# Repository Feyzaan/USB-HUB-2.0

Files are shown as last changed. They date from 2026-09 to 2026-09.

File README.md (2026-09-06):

# GL850G + TPS2044B USB Hub — Validation Board

A self-powered, 4-port USB 2.0 hub PCB built to validate independent per-port power switching and fault isolation before use in a larger project. Each downstream port can be individually enabled, current-limited, and fault-reported — a short or overcurrent event on one port never affects the others.

## Overview

Most low-cost USB hubs share power switching across all ports in a single "gang" — one fault trips every port at once. This board is designed the other way: each port has its own dedicated enable and fault-report line, driven by a hub controller running in **individual power mode**, with the actual current-limiting handled by a separate quad power-distribution switch.

This board exists purely to validate that architecture in isolation — no other subsystems, no assumptions carried over from a datasheet reference circuit without independent verification.

## Key Features

- **Independent per-port power switching** — each of the 4 downstream ports has its own enable/fault signal pair, not a shared gang-mode circuit
- **Active overcurrent protection** — a fault on one port trips only that port's power channel; the remaining ports continue operating normally
- **Self-powered architecture** — the hub sources its own downstream power rather than drawing everything from the host's USB port budget
- **Reverse-current protection** — a P-channel MOSFET on the USB-C input blocks the board's local supply from backfeeding into the host
- **USB Type-C current advertisement** — CC-line resistors advertise 1.5 A to the host instead of the USB 2.0 default of 500 mA, using passive resistors only (no PD controller)
- **Per-port status indication** — dual-color LEDs report each port's connection/fault state
- **Independent, isolated crystal oscillators** — the hub controller and any downstream logic run on separate, dedicated clock sources

## Hardware

| Function | Part |
|---|---|
| USB hub controller | Genesys Logic GL850G-MNG21 (LQFP48, individual power mode) |
| Power distribution switch | Texas Instruments TPS2044BDR (quad, independently current-limited channels) |
| Reverse-current blocking | SI2301 P-channel MOSFET |
| Host connector | USB-C (16-pin, reversible) |
| Downstream connectors | 4× USB-A |
| Status indication | Dual-color (green/amber) LEDs, one per port |

## Design Notes

- The hub controller's power-on strap pins configure port count, power-switch polarity, and per-port removable/non-removable status; several of these pins double as status-LED drivers after the strap window closes, requiring careful resistor sizing so the two functions don't interfere with each other.
- Overcurrent-report lines are open-drain and require external pull-ups — this is easy to miss if relying on a symbol's default connections rather than the manufacturer's application circuit.
- Reset sensing is derived from the raw, upstream USB VBUS rail (ahead of the reverse-blocking MOSFET) rather than the board's own regulated rail, so a cable disconnect is detected immediately rather than after the local bulk capacitance discharges.

## Status

Schematic complete and cross-checked pin-by-pin against manufacturer datasheets. PCB fabrication in progress.

## Gallery

**3D render**

<p float="left">
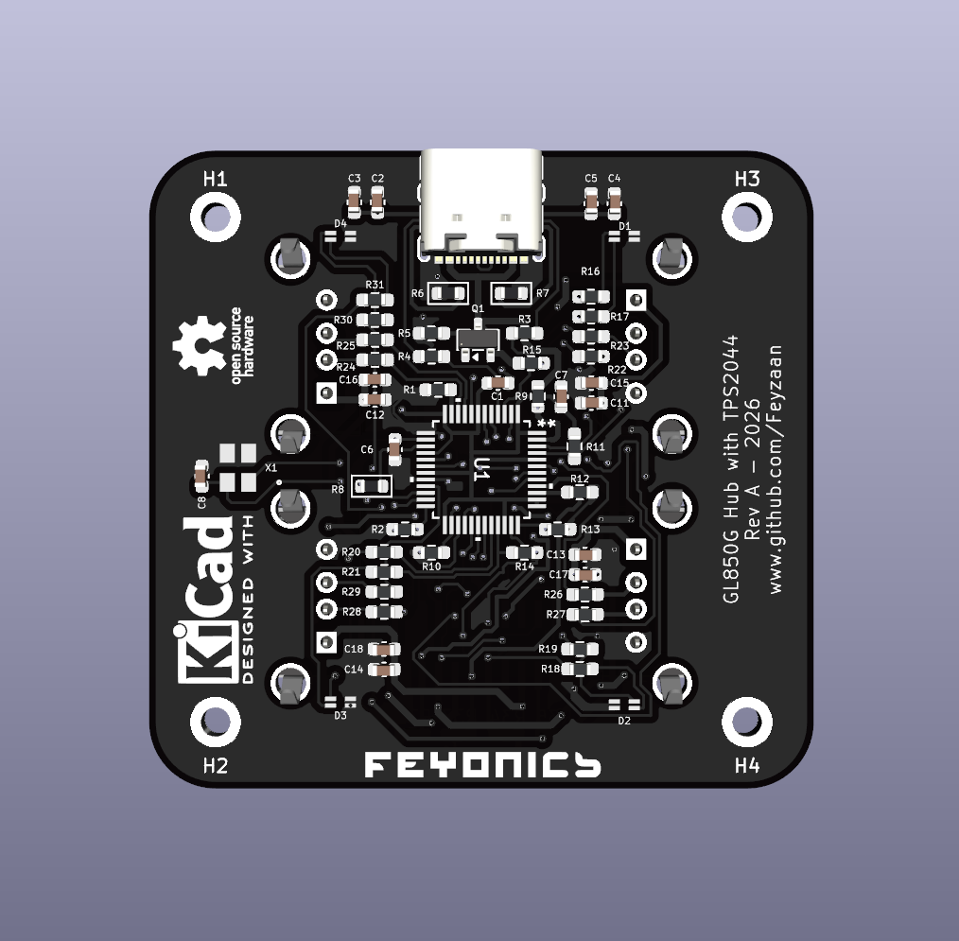
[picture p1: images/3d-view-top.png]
3D render, top view
  
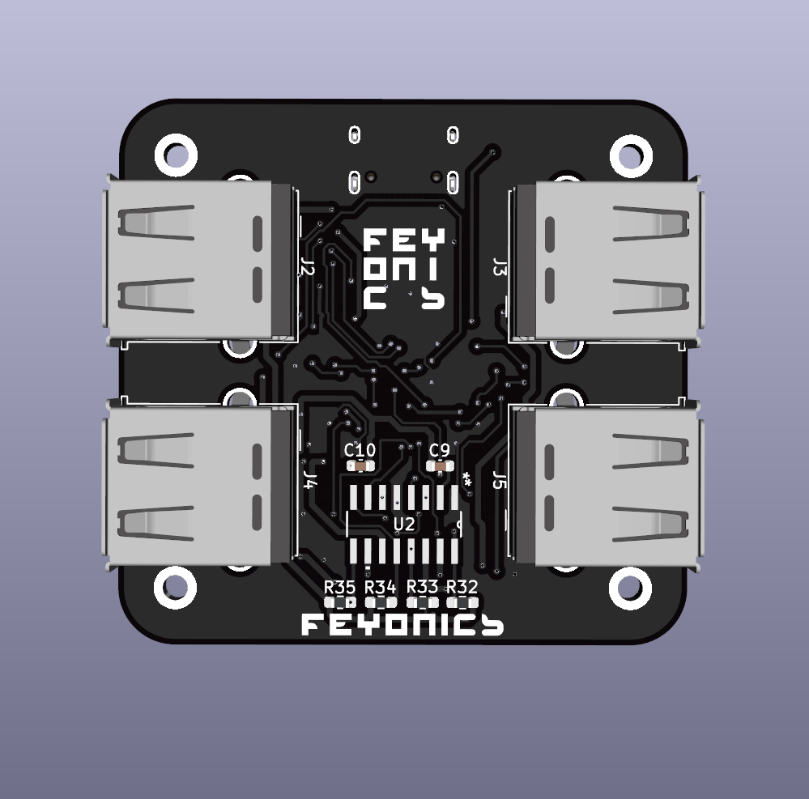
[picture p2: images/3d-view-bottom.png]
3D render, bottom view
  
</p>

**Copper layers**

<p float="left">
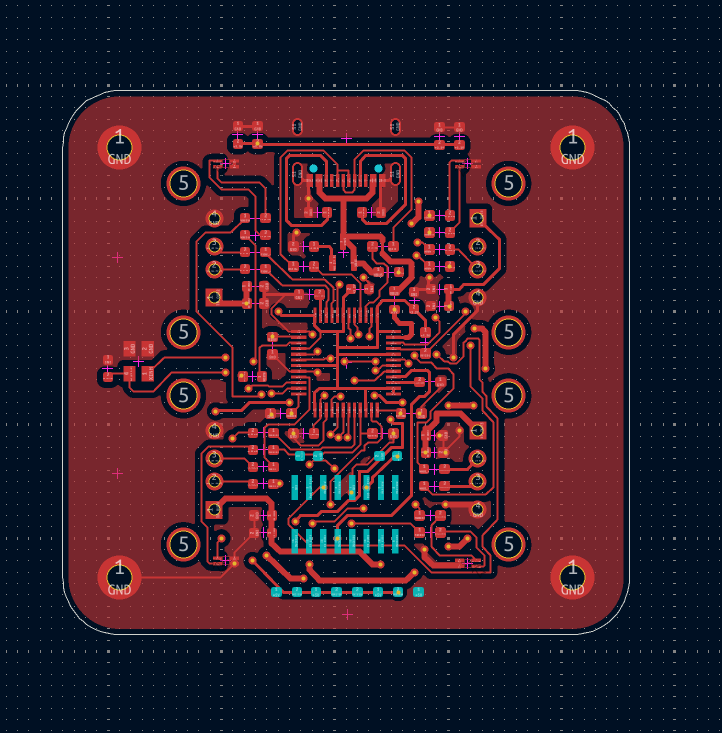
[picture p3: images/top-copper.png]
Top copper layer
  
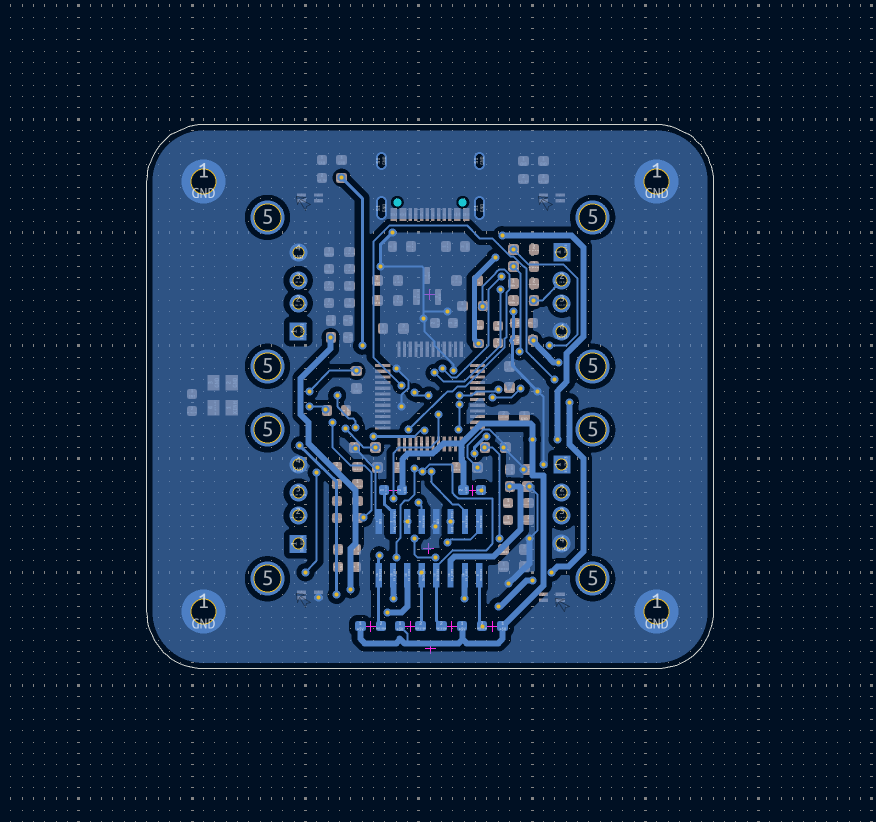
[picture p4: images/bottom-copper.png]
Bottom copper layer
  
</p>

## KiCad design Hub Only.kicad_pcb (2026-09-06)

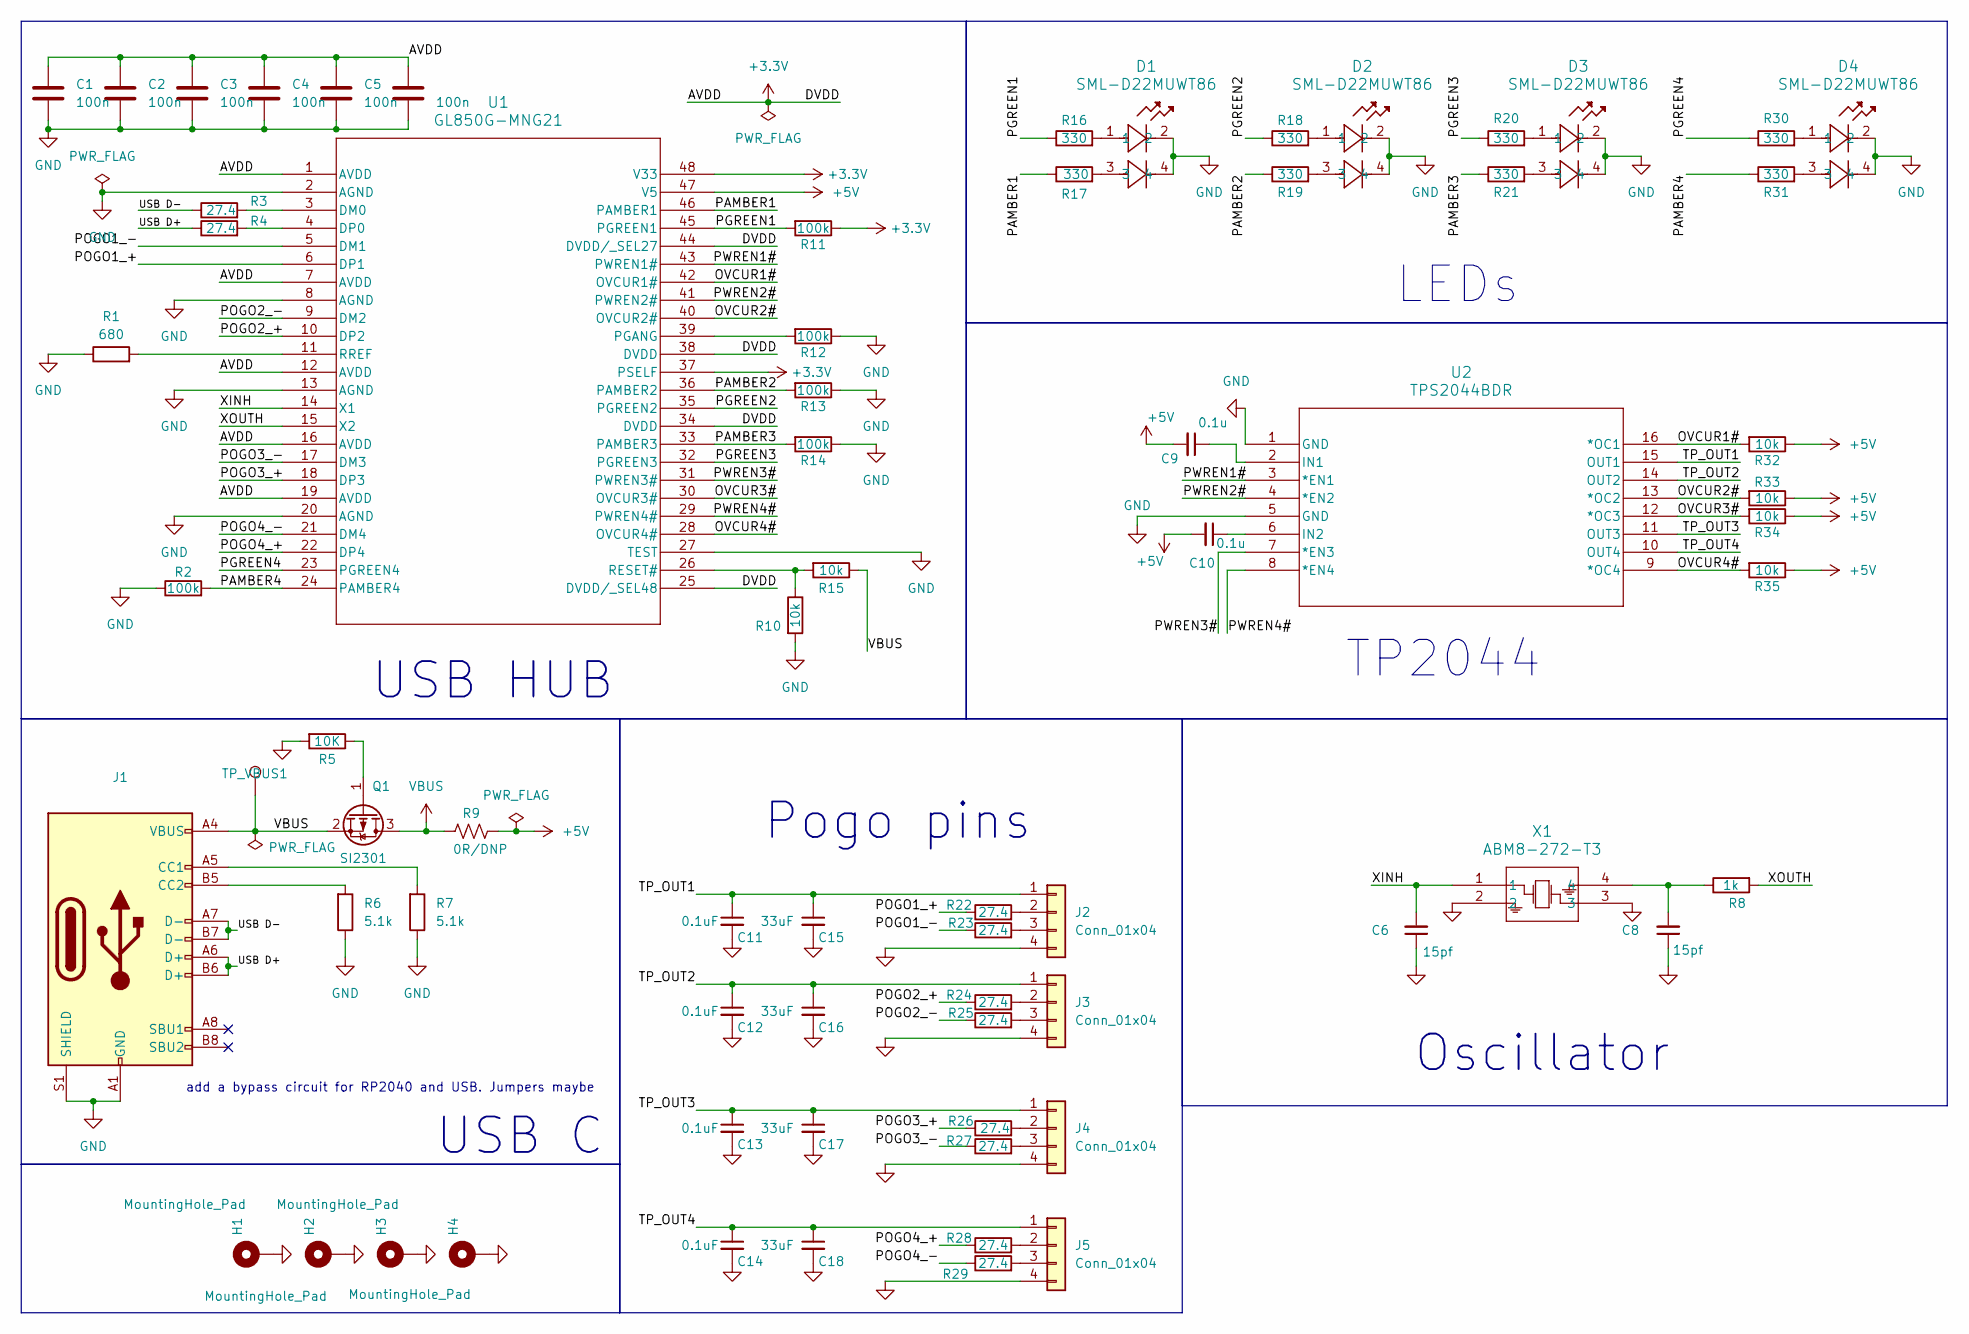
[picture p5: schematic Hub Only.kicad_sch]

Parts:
C1, C2, C3, C4, C5, C7: 100n; C_0603_1608Metric
C6, C8: 15pf; C_0603_1608Metric
C9, C10: 0.1u; C_0603_1608Metric
C11, C12, C13, C14: 0.1uF; C_0603_1608Metric
C15, C16, C17, C18: 33uF; C_0603_1608Metric
D1, D2, D3, D4: SML-D22MUWT86; LED_SML-D22_ROM
H1, H2, H3, H4: MountingHole_Pad; MountingHole_2.2mm_M2_DIN965_Pad
J1: USB_C_Receptacle_XKB_U262-16XN-4BVC11
J2, J3, J4, J5: Conn_01x04; USB_A_Molex_67643_Horizontal
Q1: SI2301; SOT-23
R1: 680; R_0603_1608Metric_Pad0.98x0.95mm_HandSolder
R2, R11, R12, R13, R14: 100k; R_0603_1608Metric_Pad0.98x0.95mm_HandSolder
R3, R4, R22, R23, R24, R25, R26, R27, R28, R29: 27.4; R_0603_1608Metric_Pad0.98x0.95mm_HandSolder
R5: 10K; R_0603_1608Metric_Pad0.98x0.95mm_HandSolder
R6, R7: 5.1k; R_0603_1608Metric
R8: 1k; R_0603_1608Metric
R9: 0R/DNP; R_0603_1608Metric
R10, R15, R32, R33, R34, R35: 10k; R_0603_1608Metric_Pad0.98x0.95mm_HandSolder
R16, R17, R18, R19, R20, R21, R30, R31: 330; R_0603_1608Metric_Pad0.98x0.95mm_HandSolder
TP_VBUS1: TestPoint; TestPoint_Pad_D1.0mm
U1: GL850G-MNG21; QFN48_GL850G_7x7-0P5_GEN
U2: TPS2044BDR; D16
X1: ABM8-272-T3; ABM8-272-T3_ABR

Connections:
+3.3V: C1.2, C2.2, C3.2, C4.2, C5.2, C7.2, R11.1, U1.1 (AVDD), U1.7 (AVDD), U1.12 (AVDD), U1.16 (AVDD), U1.19 (AVDD), U1.25 (DVDD/_SEL48), U1.34 (DVDD), U1.37 (PSELF), U1.38 (DVDD), U1.44 (DVDD/_SEL27), U1.48 (V33)
+5V: C9.2, C10.2, R9.2, R32.1, R33.1, R34.1, R35.1, U1.47 (V5)
/OVCUR1#: R32.2, U1.42 (OVCUR1#), U2.16 (*OC1)
/OVCUR2#: R33.2, U1.40 (OVCUR2#), U2.13 (*OC2)
/OVCUR3#: R34.2, U1.30 (OVCUR3#), U2.12 (*OC3)
/OVCUR4#: R35.2, U1.28 (OVCUR4#), U2.9 (*OC4)
/PAMBER1: R17.1, U1.46 (PAMBER1)
/PAMBER2: R13.2, R19.1, U1.36 (PAMBER2)
/PAMBER3: R14.2, R21.1, U1.33 (PAMBER3)
/PAMBER4: R2.2, R31.1, U1.24 (PAMBER4)
/PGREEN1: R11.2, R16.1, U1.45 (PGREEN1)
/PGREEN2: R18.1, U1.35 (PGREEN2)
/PGREEN3: R20.1, U1.32 (PGREEN3)
/PGREEN4: R30.1, U1.23 (PGREEN4)
/POGO1_+: R22.1, U1.6 (DP1)
/POGO1_-: R23.1, U1.5 (DM1)
/POGO2_+: R24.1, U1.10 (DP2)
/POGO2_-: R25.1, U1.9 (DM2)
/POGO3_+: R26.1, U1.18 (DP3)
/POGO3_-: R27.1, U1.17 (DM3)
/POGO4_+: R28.1, U1.22 (DP4)
/POGO4_-: R29.1, U1.21 (DM4)
/PWREN1#: U1.43 (PWREN1#), U2.3 (*EN1)
/PWREN2#: U1.41 (PWREN2#), U2.4 (*EN2)
/PWREN3#: U1.31 (PWREN3#), U2.7 (*EN3)
/PWREN4#: U1.29 (PWREN4#), U2.8 (*EN4)
/TP_OUT1: C11.1, C15.1, J2.1, U2.15 (OUT1)
/TP_OUT2: C12.1, C16.1, J3.1, U2.14 (OUT2)
/TP_OUT3: C13.1, C17.1, J4.1, U2.11 (OUT3)
/TP_OUT4: C14.1, C18.1, J5.1, U2.10 (OUT4)
/USB D+: J1.A6 (D+), J1.B6 (D+), R4.1
/USB D-: J1.A7 (D-), J1.B7 (D-), R3.1
/XINH: C6.2, U1.14 (X1), X1.1
/XOUTH: R8.1, U1.15 (X2)
GND: C1.1, C2.1, C3.1, C4.1, C5.1, C6.1, C7.1, C8.1, C11.2, C12.2, C13.2, C14.2, C15.2, C16.2, C17.2, C18.2, D1.2, D1.4, D2.2, D2.4, D3.2, D3.4, D4.2, D4.4, H1.1, H2.1, H3.1, H4.1, J1.A1 (GND), J1.A12 (GND), J1.B1 (GND), J1.B12 (GND), J1.S1 (SHIELD), J2.4, J3.4, J4.4, J5.4, R1.1, R2.1, R5.2, R6.2, R7.2, R10.2, R12.1, R13.1, R14.1, U1.2 (AGND), U1.8 (AGND), U1.13 (AGND), U1.20 (AGND), U1.27 (TEST), U2.1 (GND), U2.5 (GND), X1.2, X1.3
unnamed: C8.2, R8.2, X1.4
unnamed: D1.1, R16.2
unnamed: D1.3, R17.2
unnamed: D2.1, R18.2
unnamed: D2.3, R19.2
unnamed: D3.1, R20.2
unnamed: D3.3, R21.2
unnamed: D4.1, R30.2
unnamed: D4.3, R31.2
unnamed: J1.A5 (CC1), R7.1
unnamed: J1.B5 (CC2), R6.1
unnamed: J2.2, R22.2
unnamed: J2.3, R23.2
unnamed: J3.2, R24.2
unnamed: J3.3, R25.2
unnamed: J4.2, R26.2
unnamed: J4.3, R27.2
unnamed: J5.2, R28.2
unnamed: J5.3, R29.2
unnamed: Q1.1 (G), R5.1
unnamed: R3.2, U1.3 (DM0)
unnamed: R4.2, U1.4 (DP0)
unnamed: R12.2, U1.39 (PGANG)
unnamed: R10.1, R15.2, U1.26 (RESET#)
unnamed: R1.2, U1.11 (RREF)
unnamed: C9.1, U2.2 (IN1)
unnamed: C10.1, U2.6 (IN2)
VBUS: J1.A4 (VBUS), J1.A9 (VBUS), J1.B4 (VBUS), J1.B9 (VBUS), Q1.2 (S), Q1.3 (D), R9.1, R15.1, TP_VBUS1.1

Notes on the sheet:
Oscillator
USB C
USB HUB
LEDs
add a bypass circuit for RP2040 and USB. Jumpers maybe
TP2044
Pogo pins

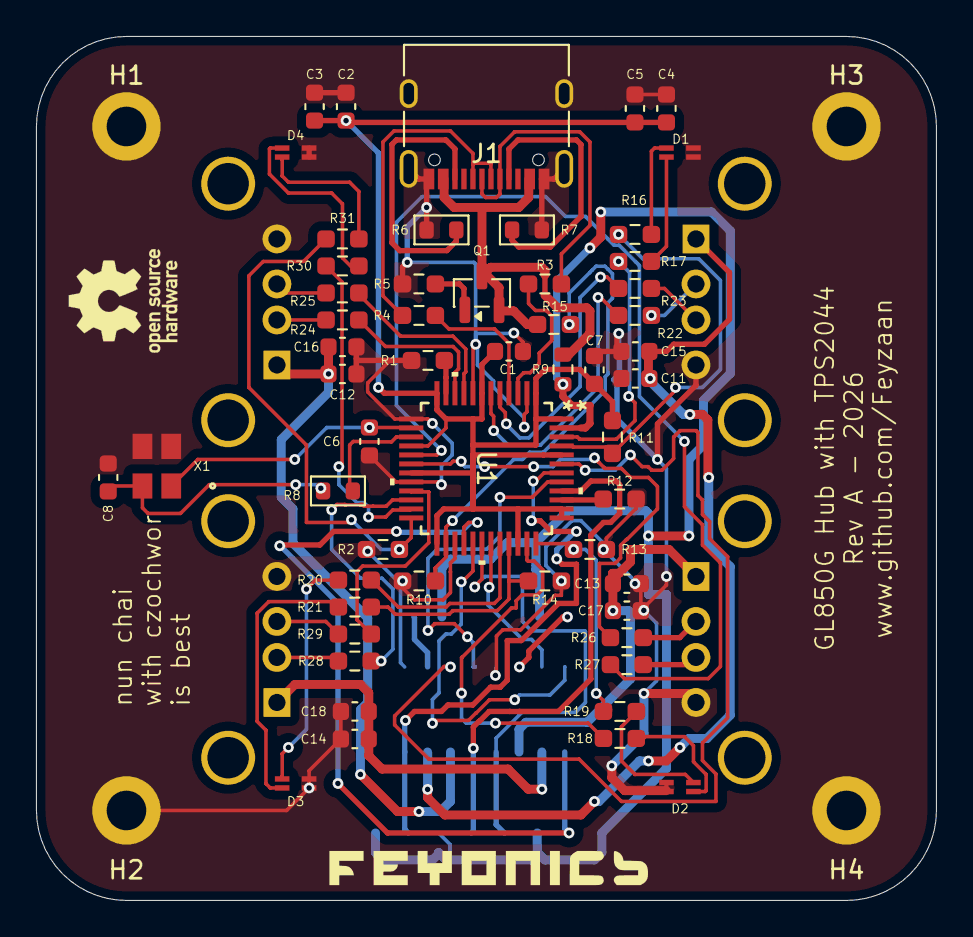
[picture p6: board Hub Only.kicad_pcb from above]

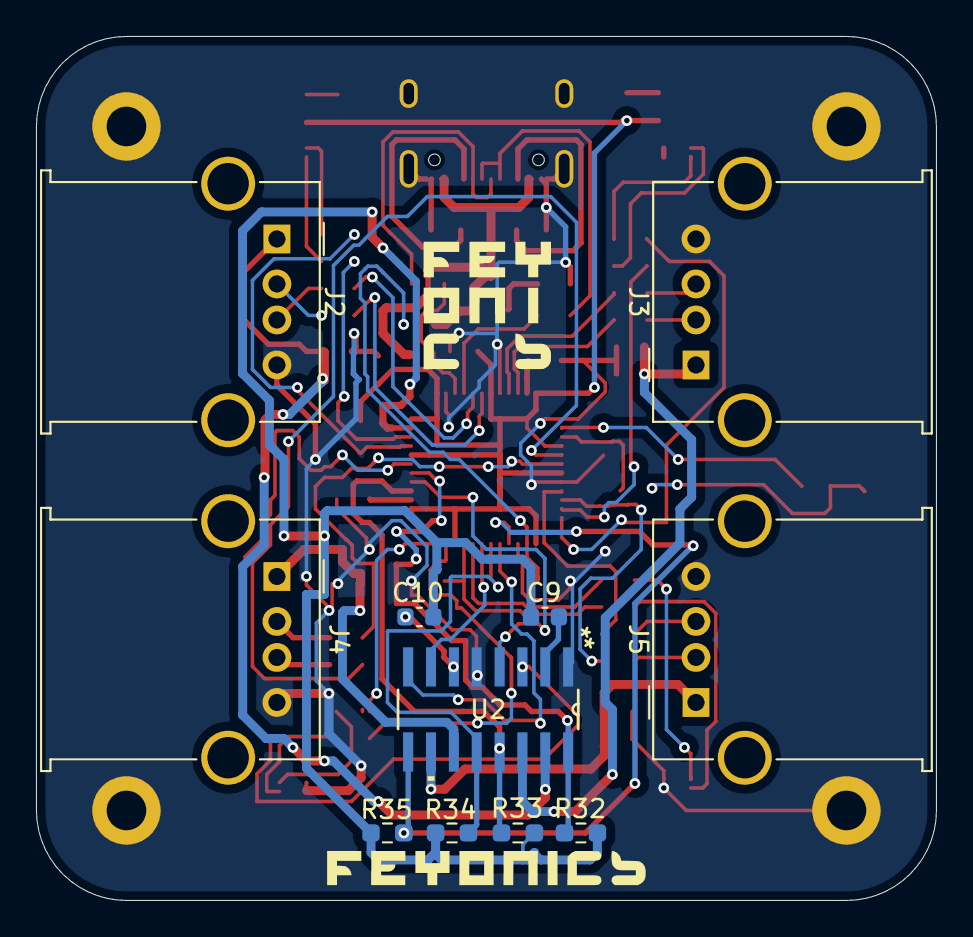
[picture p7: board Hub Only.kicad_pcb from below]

Board: 2 copper layers, 50.0 x 48.0 mm, 70 parts (11 on the bottom side), 63 nets.

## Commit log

2026-09-06 Revise README for GL850G TPS2044B USB Hub project
    Updated the README to reflect the new project focus and detailed features of the GL850G and TPS2044B USB hub validation board.
2026-09-06 Initial upload - Rev A
    [Hub Only.kicad_pcb, Hub Only.kicad_sch]
